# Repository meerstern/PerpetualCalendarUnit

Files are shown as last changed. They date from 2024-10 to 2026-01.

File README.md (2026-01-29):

# 万年カレンダーユニット　Perpetual Calendar Unit

## 概要 
  * 2.13インチ、122x250 超低消費電力LCDを用いた万年カレンダーユニットです  
  * 現在の日付、時刻、その月を表示します  
  * 精度±3.8ppmの温度補正機能付RTC SD3077を搭載しています  
  * LCD横のジョイスティックで翌月や前月等、表示月を変更することが可能です  
  * 単三電池2本で約1年前後の電池寿命です  
  * Pico-SDKを使用したソースコードを公開しています  

## 仕様  
  * ジョイスティック(カレンダー切替、時刻合わせ)、BOOTボタン、RESETボタンを搭載しています  
  * マイコンRP2040、RTC SD3077、電源管理IC XC6194を使用しています  
  * RTCのINT信号によって電源管理ICからマイコンを1分に1回、起動させています  
  * 起動後はLCD表示を更新後、シャットダウン信号を電源管理ICに送って、マイコンの電源を切ることで省電力化しています    
  * RTCのINTとジョイスティックの中央ボタンは同一信号となっており、ユーザ操作の長押しによって復帰します  
  * 単三電池2本もしくはUSB電源(USB Type-C)  
  * 時刻(RTC)保持電池 CR1220  
  * サイズ82mm x32mm x 30mm(突起部、USBコネクタ除く)

## 注意点
  * LCDはガラス製のため、強い力や衝撃を与えると破損する可能性があります     
  * 使用時はクリップ等の金属がユニット内に入り込まないように注意してください  
  * 電池寿命は使用環境や使用方法によって大きく変動するため、期間を保証するものではありません  
  * 操作時はジョイスティックの中央を3秒程度長押しして、スリープから復帰させてください  
  * ジョイスティックの応答がない場合は背面のRSTボタンを押してください  
  * 万一、画面端に点表示が残る場合はカレンダー切替等で画面を数回リフレッシュすることで解消します  
  * 告知なしに部品や仕様を変更する場合があります  
  
## 使い方  

### a.通常使用の場合  
 単三電池2個もしくはUSB Type-CをUSB電源等に接続してください  
 画面がすぐに表示されない場合はLCD右横のジョイスティックの中央を3秒程度長押ししてください  
 万一、画面端に点表示が残る場合はカレンダー切替等で画面を数回リフレッシュすることで解消します  

### b.カレンダー切替  
 ジョイスティックの中央を3秒程度長押しして、スリープから復帰させてください  
 スリープから復帰すると画面が一瞬、点滅してLCDが再度、更新されます  
 この状態でジョイスティックを上下に動かすと表示月を切り替えることが可能です  
 10秒以上放置するか、ジョイスティックの中央を再度、押すと現在の月に戻ります  
 万一、ジョイスティックの応答がない場合は背面のRSTボタンを押してください  
　
### c.日付時刻合わせ  
 ジョイスティックの中央を3秒程度長押しして、スリープから復帰させてください  
 スリープから復帰すると画面が一瞬、点滅してLCDが再度、更新されます  
 この状態でジョイスティックを左右どちらかに3秒程度長押しすると日付、時刻合わせモードに入ります  
 左右で設定項目変更、上下で数値を変更します  
 決定する場合ははジョイスティックの中央を押して設定を完了させます  
 万一、ジョイスティックの応答がない場合は背面のRSTボタンを押してください  
    
### d.ファームウェアの書換を行う場合
 PC等にUSB Type-Cを接続し、BOOTボタンを押した状態でRSTボタンを押すとUSBドライブとして認識されます  
 ファームウェアファイル(*.uf2)を認識されたUSBドライブに書き込むことでファームの書換が可能です  
 
## リリースノート
　v1.1 クロックダウンによる更なる省エネ化を実施  
　v1.2 初期状態によってスリープ復帰に失敗する不具合を修正  

## 電池交換時の確認
  * RTC電池は電源供給なしで3年以上、日時、時刻を保持することが可能です  
  * 万一、保持できなくなった場合はCR1220の電池交換を行ってください  
  * 電池交換後は日時、時刻が不定値となるため、必ず時刻、日付を再設定してください  

## 外観
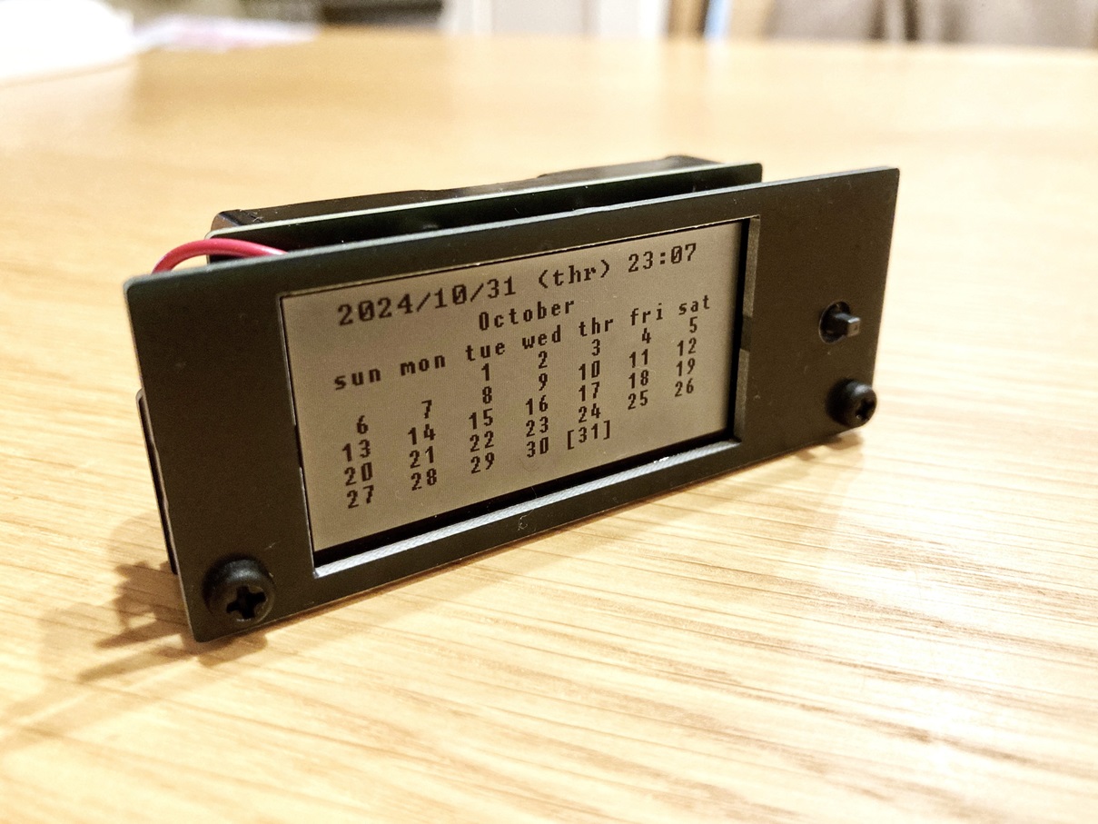
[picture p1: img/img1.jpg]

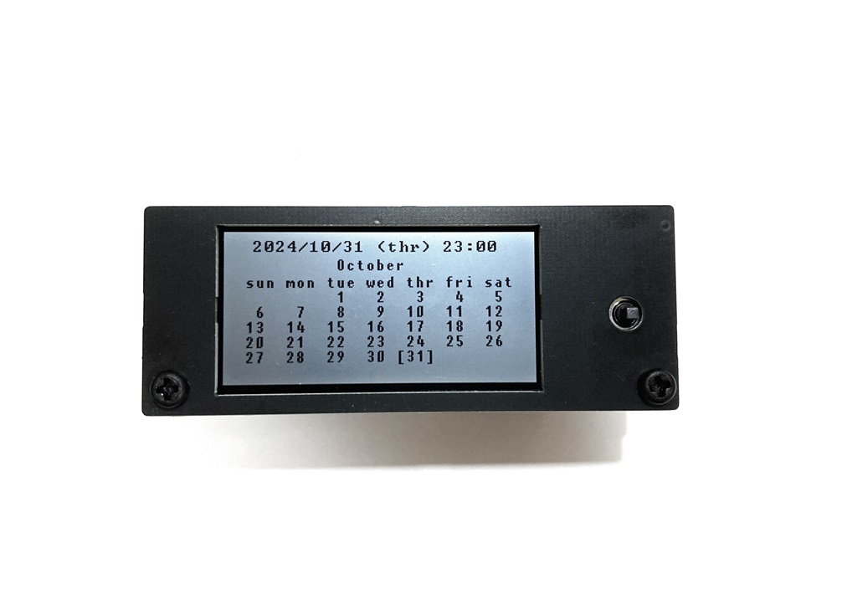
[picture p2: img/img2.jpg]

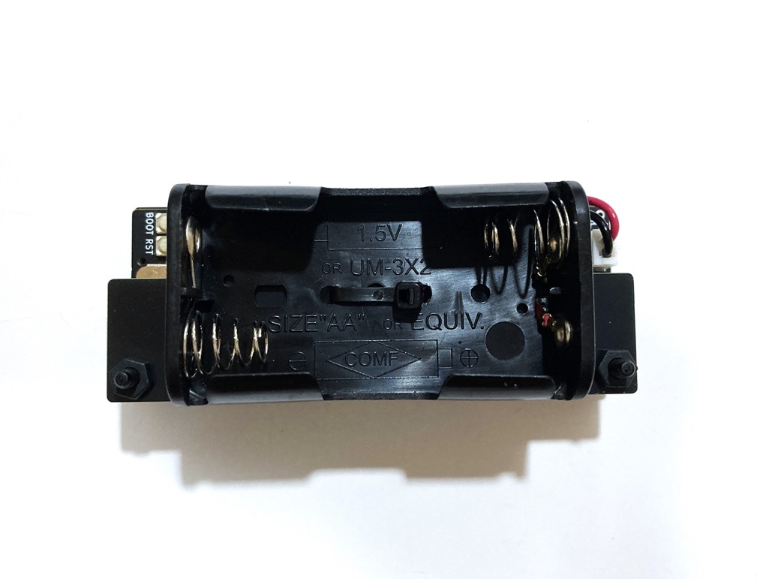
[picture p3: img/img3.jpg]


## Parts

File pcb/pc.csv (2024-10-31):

ID | 参照記号 | パッケージ | 数 | 名称 | Supplier and ref
1 | R19,R18,R17,R16,R15,R8,R1 | R_0603_1608Metric | 7 | 1k
2 | R14,R12,R11 | R_0603_1608Metric | 3 | 0
3 | C7,C34,C29,C26,C10 | C_0603_1608Metric | 5 | 0.1uF
4 | R13,R5,R2 | R_0603_1608Metric | 3 | 10k
5 | U8,U7 | SOT-363_SC-70-6 | 2 | LDSW_SiP32431
6 | IC1 | XC6194BANNERG | 1 | XC6194BANNER-G
7 | U4 | SKRHAAE010 | 1 | SKRHAAE010
8 | L1 | L_Taiyo-Yuden_MD-5050 | 1 | 100uH
9 | J4 | GROVE | 1 | Grove
10 | U3 | RP2040-QFN-56 | 1 | RP2040
11 | REF2,REF1 | MountingHole_3.2mm_M3 | 2 | MountingHole_3.2mm_M3
12 | U5 | SON-8-1EP_3x2mm_P0.5mm_EP1.4x1.6mm | 1 | W25Q16JVUX
13 | Y1 | FA238V | 1 | Crystal_GND3
14 | U6 | SO-8_5.3x6.2mm_P1.27mm | 1 | SD3077
15 | U2 | SOT-23-5 | 1 | LD3985M33R_SOT23
16 | U1 | SOT-23 | 1 | HT7733A/XC9111A331
17 | SW2 | SKRPACE010 | 1 | BOOT
18 | SW1 | SKRPACE010 | 1 | RST
19 | R10 | R_0603_1608Metric | 1 | 100k
20 | R9 | R_0603_1608Metric | 1 | 330
21 | R7,R6 | R_0603_1608Metric | 2 | 27
22 | R4,R3 | R_0603_1608Metric | 2 | 5.1k
23 | J3 | 24pin0.8mm | 1 | LCD ST7302 122x250 ZJY213S0700TG01
24 | J2 | TypeC_16Pin | 1 | TypeC16Pin
25 | J1 | JST_PH_B2B-PH-K_1x02_P2.00mm_Vertical | 1 | POW
26 | F1 | Fuse_0603_1608Metric | 1 | Fuse
27 | D1 | D_SOD-123 | 1 | D_Schottky
28 | C33,C32,C31,C30,C28,C27,C25,C23,C22,C21 | C_0603_1608Metric | 10 | 1uF
29 | C24,C20 | C_0603_1608Metric | 2 | 8p
30 | C19 | C_0603_1608Metric | 1 | 2.2u
31 | C18,C17,C15,C14,C13,C12,C11,C2,C1 | C_0603_1608Metric | 9 | 0.1u
32 | C9 | CP_Elec_6.3x3 | 1 | 10u
33 | C8,C5,C4,C3 | C_0805_2012Metric | 4 | 10uF
34 | C6 | C_0603_1608Metric | 1 | 0.01uF
35 | BT2 | 2895 | 1 | RTC CR1220

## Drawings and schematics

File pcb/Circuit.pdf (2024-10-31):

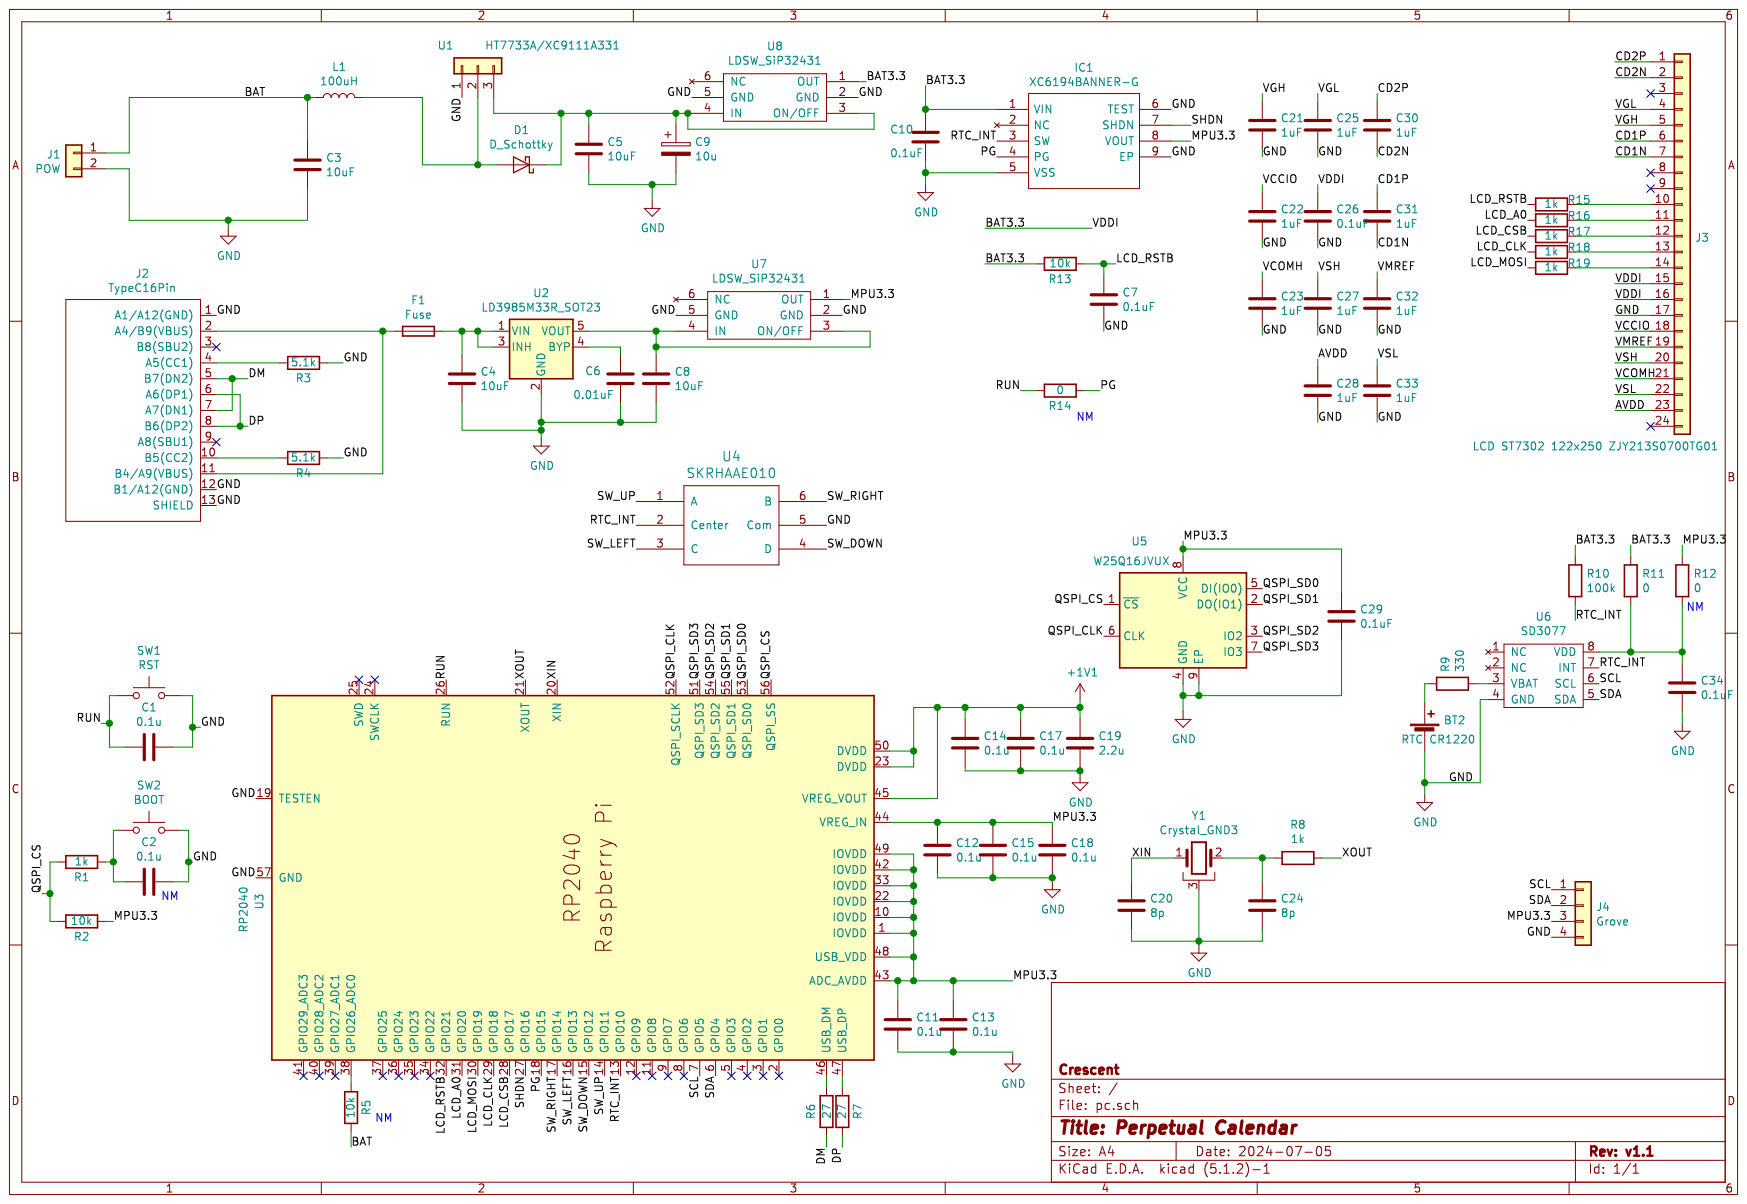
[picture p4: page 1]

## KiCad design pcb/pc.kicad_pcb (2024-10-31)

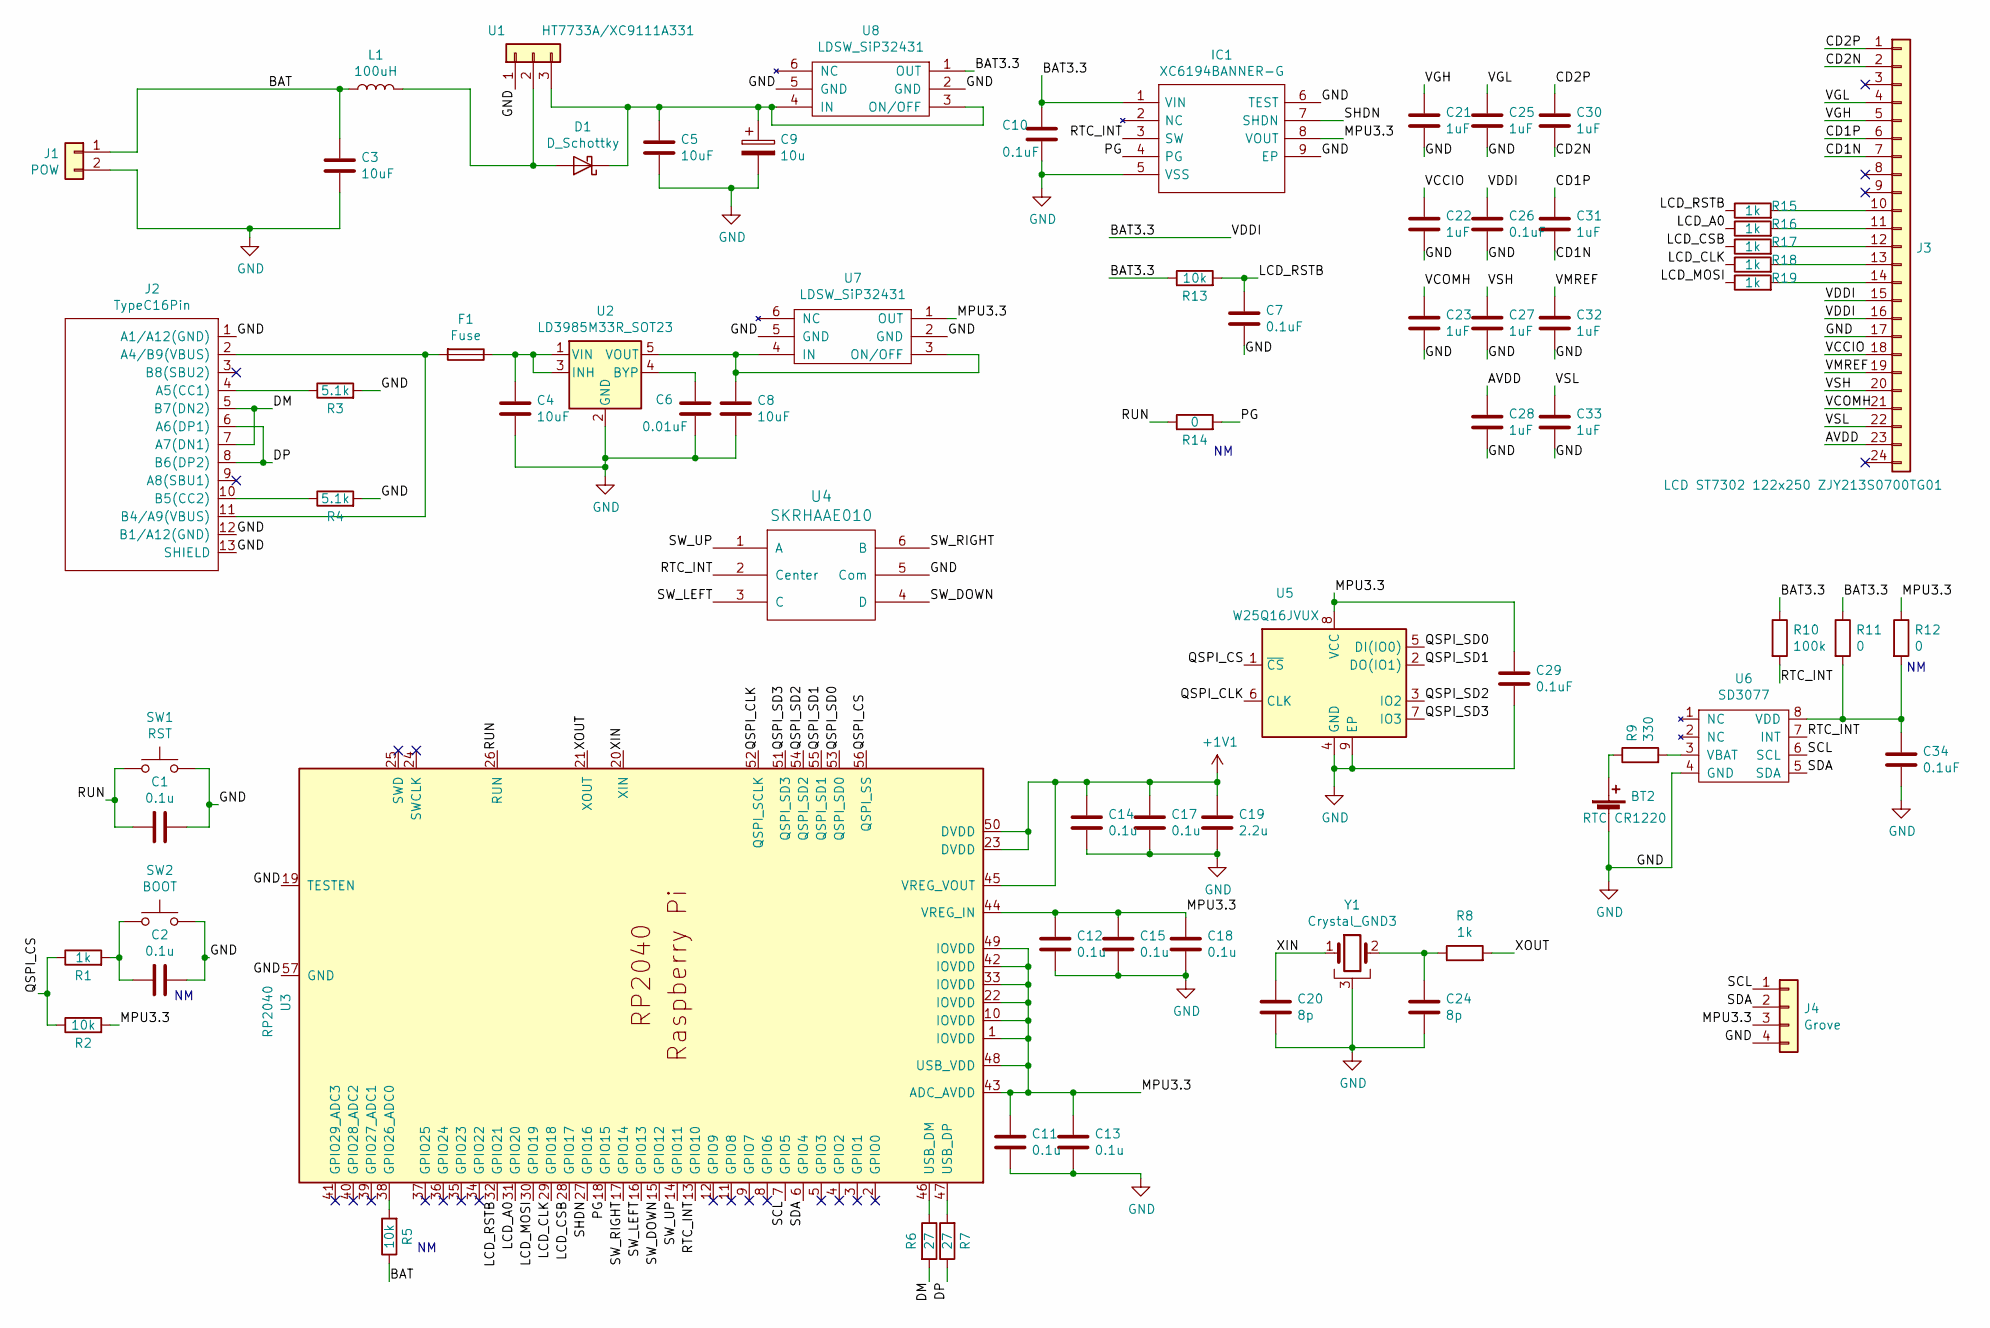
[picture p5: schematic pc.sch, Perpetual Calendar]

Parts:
BT2: RTC CR1220; 2895
C1, C2, C11, C12, C13, C14, C15, C17, C18: 0.1u; C_0603_1608Metric
C3, C4, C5, C8: 10uF; C_0805_2012Metric
C6: 0.01uF; C_0603_1608Metric
C7, C10, C26, C29, C34: 0.1uF; C_0603_1608Metric
C9: 10u; CP_Elec_6.3x3
C19: 2.2u; C_0603_1608Metric
C20, C24: 8p; C_0603_1608Metric
C21, C22, C23, C25, C27, C28, C30, C31, C32, C33: 1uF; C_0603_1608Metric
D1: D_Schottky; D_SOD-123
F1: Fuse; Fuse_0603_1608Metric
IC1: XC6194BANNER-G; XC6194BANNERG; Manufacturer_Part_Number XC6194BANNER-G; Mouser Part Number 865-XC6194BANNER-G
J1: POW; JST_PH_B2B-PH-K_1x02_P2.00mm_Vertical
J2: TypeC16Pin; TypeC_16Pin
J3: LCD ST7302 122x250 ZJY213S0700TG01; 24pin0.8mm
J4: Grove; GROVE
L1: 100uH; L_Taiyo-Yuden_MD-5050
R1, R8, R15, R16, R17, R18, R19: 1k; R_0603_1608Metric
R2, R5, R13: 10k; R_0603_1608Metric
R3, R4: 5.1k; R_0603_1608Metric
R6, R7: 27; R_0603_1608Metric
R9: 330; R_0603_1608Metric
R10: 100k; R_0603_1608Metric
R11, R12, R14: 0; R_0603_1608Metric
SW1: RST; SKRPACE010
SW2: BOOT; SKRPACE010
U1: HT7733A/XC9111A331; SOT-23
U2: LD3985M33R_SOT23; SOT-23-5
U3: RP2040; RP2040-QFN-56
U4: SKRHAAE010
U5: W25Q16JVUX; SON-8-1EP_3x2mm_P0.5mm_EP1.4x1.6mm
U6: SD3077; SO-8_5.3x6.2mm_P1.27mm
U7, U8: LDSW_SiP32431; SOT-363_SC-70-6
Y1: Crystal_GND3; FA238V

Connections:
+1V1: C14.1, C17.1, C19.1, U3.23 (DVDD), U3.45 (VREG_VOUT), U3.50 (DVDD)
/AVDD: C28.1, J3.23
/BAT: C3.1, J1.1, L1.1, R5.1
/BAT3.3: C10.1, C26.1, IC1.1 (VIN), J3.15, J3.16, R10.1, R11.1, R13.1, U8.1 (OUT)
/CD1N: C31.2, J3.7
/CD1P: C31.1, J3.6
/CD2N: C30.2, J3.2
/CD2P: C30.1, J3.1
/DM: J2.5 (B7(DN2)), J2.7 (A7(DN1)), R6.2
/DP: J2.6 (A6(DP1)), J2.8 (B6(DP2)), R7.1
/LCD_A0: R16.1, U3.31 (GPIO20)
/LCD_CLK: R18.1, U3.29 (GPIO18)
/LCD_CSB: R17.1, U3.28 (GPIO17)
/LCD_MOSI: R19.1, U3.30 (GPIO19)
/LCD_RSTB: C7.1, R13.2, R15.1, U3.32 (GPIO21)
/MPU3.3: C11.1, C12.1, C13.1, C15.1, C18.1, C29.1, IC1.8 (VOUT), J4.3, R2.2, R12.1, U3.1 (IOVDD), U3.10 (IOVDD), U3.22 (IOVDD), U3.33 (IOVDD), U3.42 (IOVDD), U3.43 (ADC_AVDD), U3.44 (VREG_IN), U3.48 (USB_VDD), U3.49 (IOVDD), U5.8 (VCC), U7.1 (OUT)
/PG: IC1.4 (PG), R14.2, U3.18 (GPIO15)
/QSPI_CLK: U3.52 (QSPI_SCLK), U5.6 (CLK)
/QSPI_CS: R1.1, R2.1, U3.56 (QSPI_SS), U5.1 (~CS)
/QSPI_SD0: U3.53 (QSPI_SD0), U5.5 (DI(IO0))
/QSPI_SD1: U3.55 (QSPI_SD1), U5.2 (DO(IO1))
/QSPI_SD2: U3.54 (QSPI_SD2), U5.3 (IO2)
/QSPI_SD3: U3.51 (QSPI_SD3), U5.7 (IO3)
/RTC_INT: IC1.3 (SW), R10.2, U3.13 (GPIO10), U4.2 (Center), U6.7 (INT)
/RUN: C1.2, R14.1, SW1.1, U3.26 (RUN)
/SCL: J4.1, U3.7 (GPIO5), U6.6 (SCL)
/SDA: J4.2, U3.6 (GPIO4), U6.5 (SDA)
/SHDN: IC1.7 (SHDN), U3.27 (GPIO16)
/SW_DOWN: U3.15 (GPIO12), U4.4 (D)
/SW_LEFT: U3.16 (GPIO13), U4.3 (C)
/SW_RIGHT: U3.17 (GPIO14), U4.6 (B)
/SW_UP: U3.14 (GPIO11), U4.1 (A)
/VCCIO: C22.1, J3.18
/VCOMH: C23.1, J3.21
/VGH: C21.1, J3.5
/VGL: C25.1, J3.4
/VMREF: C32.1, J3.19
/VSH: C27.1, J3.20
/VSL: C33.1, J3.22
/XIN: C20.1, U3.20 (XIN), Y1.1
/XOUT: R8.2, U3.21 (XOUT)
GND: BT2.2 (-), C1.1, C2.1, C3.2, C4.2, C5.2, C6.2, C7.2, C8.2, C9.2, C10.2, C11.2, C12.2, C13.2, C14.2, C15.2, C17.2, C18.2, C19.2, C20.2, C21.2, C22.2, C23.2, C24.2, C25.2, C26.2, C27.2, C28.2, C29.2, C32.2, C33.2, C34.2, IC1.5 (VSS), IC1.6 (TEST), IC1.9 (EP), J1.2, J2.1 (A1/A12(GND)), J2.12 (B1/A12(GND)), J2.13 (SHIELD), J3.17, J4.4, R3.2, R4.2, SW1.2, SW2.2, U1.1, U2.2 (GND), U3.19 (TESTEN), U3.57 (GND), U4.5 (Com), U5.4 (GND), U5.9 (EP), U6.4 (GND), U7.2 (GND), U7.5 (GND), U8.2 (GND), U8.5 (GND), Y1.3
unnamed: BT2.1 (+), R9.1
unnamed: C2.2, R1.2, SW2.1
unnamed: C4.1, F1.1, U2.1 (VIN), U2.3 (INH)
unnamed: C5.1, C9.1, D1.1 (K), U1.3, U8.3 (ON/OFF), U8.4 (IN)
unnamed: C6.1, U2.4 (BYP)
unnamed: C8.1, U2.5 (VOUT), U7.3 (ON/OFF), U7.4 (IN)
unnamed: C24.1, R8.1, Y1.2
unnamed: C34.1, R11.2, R12.2, U6.8 (VDD)
unnamed: D1.2 (A), L1.2, U1.2
unnamed: F1.2, J2.2 (A4/B9(VBUS)), J2.11 (B4/A9(VBUS))
unnamed: J2.4 (A5(CC1)), R3.1
unnamed: J2.10 (B5(CC2)), R4.1
unnamed: J3.10, R15.2
unnamed: J3.11, R16.2
unnamed: J3.12, R17.2
unnamed: J3.13, R18.2
unnamed: J3.14, R19.2
unnamed: R5.2, U3.38 (GPIO26_ADC0)
unnamed: R6.1, U3.46 (USB_DM)
unnamed: R7.2, U3.47 (USB_DP)
unnamed: R9.2, U6.3 (VBAT)

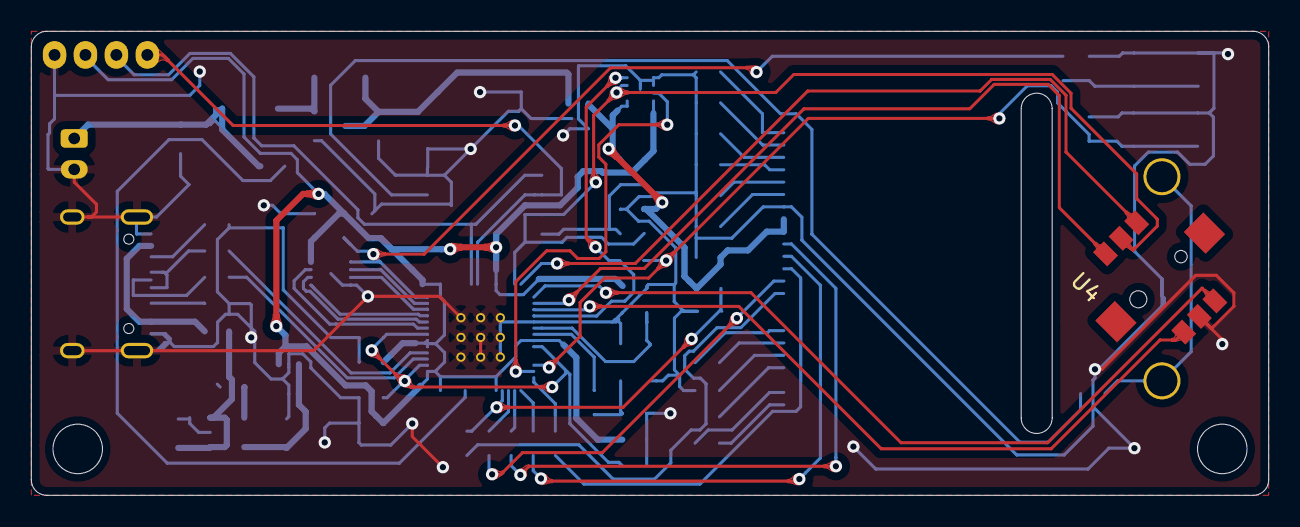
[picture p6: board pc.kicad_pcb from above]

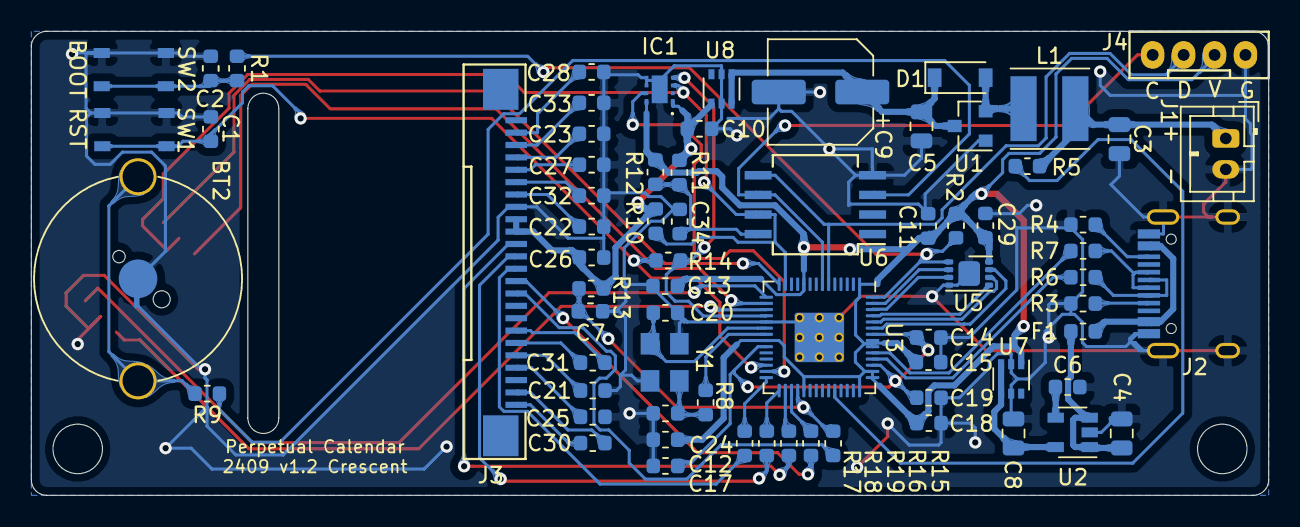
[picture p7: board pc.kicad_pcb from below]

Board: 2 copper layers, 80.0 x 30.0 mm, 74 parts (71 on the bottom side), 63 nets.

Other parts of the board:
REF1, REF2: MountingHole_3.2mm_M3

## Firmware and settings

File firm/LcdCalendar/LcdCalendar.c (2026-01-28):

/*
 *  	LcdCalendar.c
 *
 *  Copyright (c) 2024
 *  K.Watanabe, Crescentt
 *  Released under the MIT license
 *  http://opensource.org/licenses/mit-license.php
 * 
 */


#include <stdio.h>
#include <string.h>
#include <stdbool.h>
#include "pico/stdlib.h"
#include "hardware/spi.h"
#include "hardware/i2c.h"
#include "hardware/timer.h"
#include "hardware/watchdog.h"
#include "LcdSt7302.h"
#include "calendar.h"
#include "LcdCalendar.h"
#include "rtc_sd30XX.h"
#include "soft_spi.h"
#include "ugui.h"

#define LINE_OFFSET			12
#define SLEEP_COUNT_MAX		10	//After user sw 10sec, go to sleep 
#define EDIT_MODE_COUNT_MAX	3	//Enter Edit Mode


UG_GUI gui;


enum{
	EDIT_NUM_YEAR,
	EDIT_NUM_MONTH,
	EDIT_NUM_DAY,
	EDIT_NUM_HOUR,
	EDIT_NUM_MIN,
	EDIT_NUM_SEC,
	EDIT_NUM_MAX
};

volatile bool EventFlg = false;
volatile bool initialUpdate = true;
volatile bool enterSleep = false;
volatile bool editMode = false;

volatile uint8_t editPart = EDIT_NUM_YEAR;

volatile uint8_t rtc_int_old = 0;
volatile uint8_t sw_up_old = 0;
volatile uint8_t sw_down_old = 0;
volatile uint8_t sw_left_old = 0;
volatile uint8_t sw_right_old = 0;

volatile uint16_t sleepCount = 0;
volatile uint16_t editModeCount = 0;

volatile int16_t offset_month = 0;
volatile int16_t offset_year = 0;

uint8_t rtc_y;
uint8_t rtc_mon;
uint8_t rtc_d;
uint8_t rtc_h;
uint8_t rtc_min;
uint8_t rtc_s;
uint8_t rtc_w;

uint8_t edit_y=24;
uint8_t edit_mon=10;
uint8_t edit_d=1;
uint8_t edit_w=0;
uint8_t edit_h=10;
uint8_t edit_min=0;
uint8_t edit_s=0;


bool repeating_timer_callback(struct repeating_timer *t)
{  
	// Check Sleep Count
	sleepCount++;
	if( sleepCount > SLEEP_COUNT_MAX )
	{
		//Undo & Set Today
		offset_month = rtc_mon;
		offset_year = rtc_y;
		initialUpdate = true;		
		enterSleep = true;
	}

	//Check Edit Count	
	if( gpio_get(PIN_SW_LEFT)==0 || gpio_get(PIN_SW_RIGHT)==0)
		editModeCount++;
	else
		editModeCount=0;

	if( editModeCount > EDIT_MODE_COUNT_MAX )
		editMode = true;

    return true;
}

void checkUserInput()
{
	bool hasInput = false;
	uint8_t rtc_int = gpio_get(PIN_RTCINT);
	uint8_t sw_up = gpio_get(PIN_SW_UP);
	uint8_t sw_down = gpio_get(PIN_SW_DOWN);
	uint8_t sw_right = gpio_get(PIN_SW_RIGHT);
	uint8_t sw_left = gpio_get(PIN_SW_LEFT);
	
	if( rtc_int_old == 0 &&  rtc_int == 1 )
	{
		if(editMode)
		{
			//Set RTC
			SetRtcDate(edit_y, edit_mon, edit_d);
			SetRtcTime(edit_h, edit_min, edit_s);
			SetRtcWeek(edit_w);
			editMode = false;
		}
		else
		{
			offset_month = rtc_mon;
			offset_year = rtc_y;
		}
		
		hasInput = true;
	}
		
	
	if( sw_down_old == 0 && sw_down == 1 )
	{
		if(editMode)
		{
			switch(editPart)
			{
				case EDIT_NUM_YEAR:
					edit_y++;
					break;
				case EDIT_NUM_MONTH:
					if(edit_mon<12)
						edit_mon++;	
					else
						edit_mon=1;	
					break;
				case EDIT_NUM_DAY:
					if(edit_d<31)
						edit_d++;
					else
						edit_d=1;
					break;
				case EDIT_NUM_HOUR:
					if(edit_h<23)
						edit_h++;
					else
						edit_h=0;
					break;
				case EDIT_NUM_MIN:
					if(edit_min<59)
						edit_min++;
					else
						edit_min=0;
					break;
				case EDIT_NUM_SEC:
					if(edit_s<59)
						edit_s++;
					else
						edit_s=0;
					break;
				default:
					break;
			}

		}
		else
		{
			offset_month++;
			if( offset_month > 12 )
			{
				offset_month = 1;
				offset_year++;
			}
		}
		hasInput = true;
	}
		

	if( sw_up_old == 0 && sw_up ==1 )
	{
		if(editMode)
		{
			switch(editPart)
			{

				case EDIT_NUM_YEAR:
					edit_y--;
					break;
				case EDIT_NUM_MONTH:
					if(edit_mon>1)
						edit_mon--;	
					else
						edit_mon=12;	
					break;
				case EDIT_NUM_DAY:
					if(edit_d>1)
						edit_d--;
					else
						edit_d=31;
					break;
				case EDIT_NUM_HOUR:
					if(edit_h>1)
						edit_h--;
					else
						edit_h=23;	
					break;
				case EDIT_NUM_MIN:
					if(edit_min>1)
						edit_min--;
					else
						edit_min=59;
					break;
				case EDIT_NUM_SEC:
					if(edit_s>1)
						edit_s--;
					else
						edit_s=59;
					break;
				default:
					break;
			}

		}
		else
		{
			offset_month--;
			if( offset_month <= 0 )
			{
				offset_month = 12;
				offset_year--;
			}
		}
		hasInput = true;
	}
		

	if( sw_left_old == 0 && sw_left == 1 )
	{
		if( editMode && editPart > 0)
		{
			editPart--;
		}
		hasInput = true;
	}
		

	if(	sw_right_old == 0 && sw_right == 1)
	{
		if( editMode && editPart < EDIT_NUM_SEC)
		{
			editPart++;
		}
		hasInput = true;
	}
		

	if( hasInput == true )
	{
		sleepCount = 0;
		initialUpdate = true;
	}
	rtc_int_old = rtc_int;
	sw_up_old = sw_up;
	sw_down_old = sw_down;
	sw_left_old = sw_left;
	sw_right_old = sw_right;
}


void pset(UG_S16 x, UG_S16 y, UG_COLOR col)
{
	uint16_t c = col;
	if( c!=0 )
		c = 1;
	LcdSetPoint(x, y, c);
}

int main()
{
	set_sys_clock_khz(36000, true);//Clock down to 36MHz
	stdio_init_all();

	// I2C Initialisation. Using it at 100Khz.
    i2c_init(I2C_PORT, 100*1000);
    
    gpio_set_function(I2C_SDA, GPIO_FUNC_I2C);
    gpio_set_function(I2C_SCL, GPIO_FUNC_I2C);
    gpio_pull_up(I2C_SDA);
    gpio_pull_up(I2C_SCL);
 
    // Chip select is active-low
    gpio_init(PIN_CS);
	gpio_set_dir(PIN_CS, GPIO_OUT);
    gpio_put(PIN_CS, 1);
	
	gpio_init(PIN_RST);
	gpio_set_dir(PIN_RST, GPIO_OUT);
    gpio_put(PIN_RST, 0);
	gpio_init(PIN_DC);
	gpio_set_dir(PIN_DC, GPIO_OUT);
    gpio_put(PIN_DC, 1);


	//Joystick IO Settings
	gpio_init(PIN_RTCINT);
	gpio_set_dir(PIN_RTCINT, GPIO_IN);
	gpio_pull_up(PIN_RTCINT);

	
	gpio_init(PIN_SW_UP);
	gpio_set_dir(PIN_SW_UP, GPIO_IN);
	gpio_pull_up(PIN_SW_UP);

	
	gpio_init(PIN_SW_DOWN);
	gpio_set_dir(PIN_SW_DOWN, GPIO_IN);
	gpio_pull_up(PIN_SW_DOWN);

	
	gpio_init(PIN_SW_LEFT);
	gpio_set_dir(PIN_SW_LEFT, GPIO_IN);
	gpio_pull_up(PIN_SW_LEFT);

	gpio_init(PIN_SW_RIGHT);
	gpio_set_dir(PIN_SW_RIGHT, GPIO_IN);
	gpio_pull_up(PIN_SW_RIGHT);

	//XC6194 Load Switch Settings
	gpio_init(PIN_SHDN);
	gpio_set_dir(PIN_SHDN, GPIO_OUT);
    gpio_put(PIN_SHDN, 0);

	SoftSpiInit();

	DisableRtcIntPin();
	EnableRtcI2CInVbat();
	EnableRtcIntPin();
	EnableRtcOneMinInt();
	
	InitLcdSt7302();
	UG_Init(&gui, pset, 250, 122);
  	UG_FillScreen(C_WHITE);
	UG_SelectGUI(&gui);

	struct repeating_timer timer;
    add_repeating_timer_ms(1000, repeating_timer_callback, NULL, &timer);
	
	if( gpio_get(PIN_RTCINT) == 0 )	//Still RTCINT is low unless Rtc Interrupt Reset -> User Input
	{
		enterSleep = false;
	}
	else
	{
		enterSleep = true;
	}

	checkUserInput();
	GetRtcDateTime(&rtc_y,&rtc_mon,&rtc_d,&rtc_h,&rtc_min,&rtc_s);
	offset_month = rtc_mon;
	offset_year = rtc_y;
		
	while (true)
	{
		
		checkUserInput();

		if( initialUpdate == true || editMode == true )
		{
			if(initialUpdate==true)
				LcdClear();
			LcdEnableInversion(false);
			GetRtcDateTime(&rtc_y, &rtc_mon, &rtc_d, &rtc_h, &rtc_min, &rtc_s);
			GetRtcWeek(&rtc_w);

	
			char dateTime[60]={'\0'}; 
			char dateWeek[60]={'\0'}; 
			char dateMonth[60]={'\0'};
			char dateLine0[60]={'\0'};
			char dateLine1[60]={'\0'};
			char dateLine2[60]={'\0'};
			char dateLine3[60]={'\0'};
			char dateLine4[60]={'\0'};
			char dateLine5[60]={'\0'};
			char dateTmp[60]={'\0'};
			char str3[] = " sun mon tue wed thr fri sat";
					
			if(editMode)
			{
				edit_w = dayofweek(edit_y, edit_mon, edit_d);
				
				if( edit_w != -1 )
					GetWeekString(edit_w, dateWeek);
				
				switch (editPart)
				{
					case EDIT_NUM_YEAR:
						sprintf(dateTime,"[20%2d]/%2d/%2d %02d:%02d:%02d", edit_y, edit_mon, edit_d, edit_h, edit_min, edit_s); 
						break;
					case EDIT_NUM_MONTH:
						sprintf(dateTime,"20%2d/[%2d]/%2d %02d:%02d:%02d", edit_y, edit_mon, edit_d, edit_h, edit_min, edit_s); 
						break;					
					case EDIT_NUM_DAY:
						sprintf(dateTime,"20%2d/%2d/[%2d] %02d:%02d:%02d", edit_y, edit_mon, edit_d, edit_h, edit_min, edit_s); 
						break;
					case EDIT_NUM_HOUR:
						sprintf(dateTime,"20%2d/%2d/%2d [%02d]:%02d:%02d", edit_y, edit_mon, edit_d, edit_h, edit_min, edit_s); 
						break;
					case EDIT_NUM_MIN:
						sprintf(dateTime,"20%2d/%2d/%2d %02d:[%02d]:%02d", edit_y, edit_mon, edit_d, edit_h, edit_min, edit_s); 
						break;
					case EDIT_NUM_SEC:
						sprintf(dateTime,"20%2d/%2d/%2d %02d:%02d:[%02d]", edit_y, edit_mon, edit_d, edit_h, edit_min, edit_s); 
						break;
					default:
						break;
				}
			}
			else
			{
				GetWeekString(rtc_w, dateWeek);
				//sprintf(dateTime,"20%2d/%2d/%2d (%s) %02d:%02d:%02d",rtc_y,rtc_mon,rtc_d,dateWeek,(int)rtc_h,(int)rtc_min,(int)rtc_s);
				sprintf(dateTime,"20%2d/%2d/%2d (%s) %02d:%02d         ",rtc_y,rtc_mon,rtc_d,dateWeek,(int)rtc_h,(int)rtc_min); 
			}


			UG_FontSelect(&FONT_8X12);
			if(editMode)
				UG_PutString(4,6,dateTime);
			else
				UG_PutString(24,6,dateTime);

			if( offset_month == rtc_mon && offset_year == rtc_y )
			{
				GetMonthString(rtc_mon, dateMonth);
				GetCalendarString(rtc_y, rtc_mon, rtc_d, 0, dateLine0);
				GetCalendarString(rtc_y, rtc_mon, rtc_d, 1, dateLine1);
				GetCalendarString(rtc_y, rtc_mon, rtc_d, 2, dateLine2);
				GetCalendarString(rtc_y, rtc_mon, rtc_d, 3, dateLine3);
				GetCalendarString(rtc_y, rtc_mon, rtc_d, 4, dateLine4);
				GetCalendarString(rtc_y, rtc_mon, rtc_d, 5, dateLine5);
				UG_FontSelect(&FONT_7X12);
				if( 3<=rtc_mon && rtc_mon<=7 )
					UG_PutString(104,22,dateMonth);
				else
					UG_PutString(90,22,dateMonth);				
			}
			else
			{				
				GetMonthString(offset_month, dateMonth);
				sprintf(dateTmp,"20%2d/%s",offset_year, dateMonth);
				strcpy(dateMonth,dateTmp); 
				GetCalendarString(offset_year, offset_month, 0, 0, dateLine0);
				GetCalendarString(offset_year, offset_month, 0, 1, dateLine1);
				GetCalendarString(offset_year, offset_month, 0, 2, dateLine2);
				GetCalendarString(offset_year, offset_month, 0, 3, dateLine3);
				GetCalendarString(offset_year, offset_month, 0, 4, dateLine4);
				GetCalendarString(offset_year, offset_month, 0, 5, dateLine5);
				UG_FontSelect(&FONT_7X12);
				UG_PutString(80,22,dateMonth);
			}


			UG_FontSelect(&FONT_7X12);
			UG_PutString(10,36,str3);
			UG_PutString(10,36+1*LINE_OFFSET,dateLine0);
			UG_PutString(10,36+2*LINE_OFFSET,dateLine1);
			UG_PutString(10,36+3*LINE_OFFSET,dateLine2);
			UG_PutString(10,36+4*LINE_OFFSET,dateLine3);
			UG_PutString(10,36+5*LINE_OFFSET,dateLine4);
			UG_PutString(10,36+6*LINE_OFFSET,dateLine5);

			LcdUpdate();
			//sleep_ms(1);
			LcdDispEnable(true);
			initialUpdate = false;
		}
								
		if( enterSleep == true )
		{
			if( gpio_get(PIN_RTCINT) == 0 )
			{
				DisableRtcIntPin();
				EnableRtcIntPin();
				EnableRtcOneMinInt();				
				if( gpio_get(PIN_RTCINT) == 0 )
					watchdog_reboot(0,0,0);//Reboot
			}

			LcdEnableLowPowerMode(true);


			//Change LCD IO Direction for MPU Shutdown to avoid from LCD Reset
			gpio_init(PIN_RST);
			gpio_set_dir(PIN_RST, GPIO_IN);
			sleep_ms(1);
			gpio_put(PIN_SHDN, 1);//MPU Power Shutdown for Battery
			sleep_ms(10);
			
			//For USB Power Use
			while(gpio_get(PIN_RTCINT) == 1);
			watchdog_reboot(0,0,0);//Reboot
		}
		
		sleep_ms(10);
					
	}

    return 0;
}

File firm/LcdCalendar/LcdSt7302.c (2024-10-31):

/*
 *  	LcdSt7302.c
 *
 *  Copyright (c) 2024
 *  K.Watanabe, Crescentt
 *  Released under the MIT license
 *  http://opensource.org/licenses/mit-license.php
 * 
 *  For the ST7302 initialization sequence,  refer below link.
 *  https://github.com/zhcong/ST7302-for-arduino
 */

#include <stdlib.h>
#include <stdio.h>
#include <stdbool.h>
#include <math.h>
#include <string.h>

#include "pico/stdlib.h"
#include "soft_spi.h"
#include "LcdCalendar.h"
#include "LcdSt7302.h"


#define LCD_WIDTH	250
#define LCD_HIGHT	122

/* Command Table1 */
#define CMD_NOP                 0x00
#define CMD_SOFT_RESET          0x01
#define CMD_READ_ID             0x04
#define CMD_READ_STATUS         0x09
#define CMD_SLEEP_IN            0x10
#define CMD_SLEEP_OUT           0x11
#define CMD_PARTIAL_ON          0x12
#define CMD_PARTIAL_OFF         0x13
#define CMD_INVERSION_OFF       0x20
#define CMD_INVERSION_ON        0x21
#define CMD_DISP_OFF            0x28
#define CMD_DISP_ON             0x29
#define CMD_COL_ADDR_SET        0x2A
#define CMD_ROW_ADDR_SET        0x2B
#define CMD_MEM_WRITE           0x2C
#define CMD_MEM_READ            0x2E
#define CMD_TEARING_OFF         0x34
#define CMD_TEARING_ON          0x35
#define CMD_MEM_ACCESS_CTRL     0x36
#define CMD_VERTICAL_ADDR       0x37
#define CMD_HIGH_POWER_MODE     0x38
#define CMD_LOW_POWER_MODE      0x39
#define CMD_DATA_FORMAT_SEL     0x3A
#define CMD_WRITE_MEM_CNTI      0x3C
#define CMD_READ_MEM_CNTI       0x3E
#define CMD_TEAR_SCANLINE       0x44
#define CMD_READ_ID1            0xDA
#define CMD_READ_ID2            0xDB
#define CMD_READ_ID3            0xDC

/* Command Table2 */
#define CMD_GATE_TIMING         0x73
#define CMD_DUTY                0xB0
#define CMD_FIRST_GATE          0xB1
#define CMD_FRAME_RATE          0xB2
#define CMD_VCOM_EQ_EN          0xB3
#define CMD_UPDATE_GATE_EQ      0xB4
#define CMD_DESTRESS_GATE_EQ    0xB5
#define CMD_PANEL               0xB8
#define CMD_SOURCE              0xB9
#define CMD_CLEAR_RAM1          0xBA
#define CMD_CLEAR_RAM2          0xBB
#define CMD_GATE_VOLTAGE        0xC0
#define CMD_SOURCE_VOLTAGE1     0xC1
#define CMD_SOURCE_VOLTAGE2     0xC2
#define CMD_OSC_EN              0xC7
#define CMD_VCOMH_VOLTAGE       0xCB
#define CMD_ID1                 0xCC
#define CMD_ID2                 0xCD
#define CMD_ID3                 0xCE
#define CMD_BOOSTER_EN          0xD1
#define CMD_SOURCE_VOLTAGE_SEL  0xD6
#define CMD_NVM_LOAD            0xD7
#define CMD_SPI_INPUT_SEL       0xE4
#define CMD_NVM_READ            0xE9
#define CMD_NVM_LOAD_EN         0xEB
#define CMD_EXTB_CTRL           0xEC
#define CMD_NVM_WR_RD           0xF8
#define CMD_NVM_PRG             0xFA
#define CMD_NVM_READ_EN         0xFB
#define CMD_NVM_PRG_EN          0xFC

#define IsCMD                   1
#define IsPRM                   0

#define VAL_CLEAR_RAM_ON            0xE3
#define VAL_CLEAR_RAM_OFF           0x23
#define VAL_NVM_LOAD_NOT_TRIGGERD   0x02
#define VAL_NVM_LOAD_EN_VOL_EN_ID   0x68
#define VAL_BOOSTER_EN              0x01
#define VAL_GATE_VOLTAGE_P12V_N5V   0x80
#define VAL_SOURCE_VOLTAGE1_5V      0x28
#define VAL_SOURCE_VOLTAGE1_3_5V    0x14
#define VAL_SOURCE_VOLTAGE1_1_5V    0x00
#define VAL_SOURCE_VOLTAGE2_0V      0x00
#define VAL_VCOMH_VOLTAGE_4V        0x14
#define VAL_GATE_EQ_LEFT_EN         0xE5
#define VAL_GATE_EQ_2ND_PRM         0x66    //0x77
#define VAL_GATE_EQ_3RD_PRM         0xF1
#define VAL_GATE_EQ_4TH_PRM         0xFF
#define VAL_GATE_EQ_5TH_PRM         0xFF
#define VAL_GATE_EQ_6TH_PRM         0x4F
#define VAL_GATE_EQ_7TH_PRM         0xF1
#define VAL_GATE_EQ_8TH_PRM         0xFF
#define VAL_GATE_EQ_9TH_PRM         0xFF
#define VAL_GATE_EQ_10TH_PRM        0x4F
#define VAL_OSC_EN1                 0xA6
#define VAL_OSC_EN2                 0xE9
#define VAL_DUTY_250                0x64
#define VAL_MEM_ACCESS_MV           0x20
#define VAL_DATA_FORMAT_ON_3WIRE    0x11
#define VAL_SOURCE_CLEAR_OFF        0x23
#define VAL_PANEL_FRAME_TWO_LINE    0x09 
#define VAL_COL_ADDR1               0x05
#define VAL_COL_ADDR2               0x36
#define VAL_ROW_ADDR1               0x00
#define VAL_ROW_ADDR2               0xC7
#define VAL_SOURCE_CLEAR_ON         0xE3
#define VAL_COL_ADDR                0x19
#define VAL_ROW_ADDR                0x00  

uint8_t *lcdBuffer;
uint32_t lcdBufferSize;

uint16_t lcdByteWidth;
uint16_t lcdByteHight;


static void toggleLcdReset()
{
	gpio_put(PIN_RST, 0);
	sleep_ms(3);//10->3 For Clock Down	
	gpio_put(PIN_RST, 1);
	gpio_put(PIN_DC, 1);
	sleep_ms(30);//100->30 For Clock Down
}

static uint16_t calcByte(uint16_t x, uint16_t y)
{
	return (x-1)/2*3+(y/4)+(y/12)*(250+122-3);
}

static uint16_t calcBit(uint16_t x, uint16_t y)
{
	return ((x+1)%2)*(6-(y%4)*2)+((x)%2)*(7-(y%4)*2);
}

static uint8_t bitSet(uint8_t number, uint8_t n)
{
    return number | ((uint8_t)1 << n);
}

static uint8_t bitClear(uint8_t number, uint8_t n)
{
    return number & ~((uint8_t)1 << n);
}

static void writeSpiData(uint8_t data, bool isCmd )
{
	uint8_t wdata[1];
	wdata[0]=data;
	gpio_put(PIN_CS, 0);
    if(isCmd)
	    gpio_put(PIN_DC, 0);
	sleep_us(10);
	//spi_write_blocking(SPI_PORT,wdata,1);
	SoftSpiTransferByte(wdata[0]);
	sleep_us(50);
	gpio_put(PIN_CS, 1);
	gpio_put(PIN_DC, 1);
}
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

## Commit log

2024-10-31 Add pcb files
    [pc-B_Cu.gbr, pc-B_Mask.gbr, pc-B_Paste.gbr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]
2026-01-28 Fix Update Fail of RTC
    [LcdCalendar.c, rtc_sd30XX.c]
